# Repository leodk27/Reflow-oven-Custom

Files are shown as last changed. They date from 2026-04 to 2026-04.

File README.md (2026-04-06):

# Reflow Oven Controller  

### KES – Kwas Engineering Solutions  

---

## Overview

This is a controller for a reflow oven.  

---

## System

The system has three parts:

- Measurement (temperature)  
- Control (microcontroller)  
- Power switching (heater)  

---

## Hardware

- Microcontroller  
- Thermocouple interface  
- Triac switching stage  
- Power supply (internal and external)  

---

## Firmware

- Runs the temperature profile  
- Handles faults  
- Communicates over custom RJ45 service port  

---

## Safety

- High and low voltage are separated  
- Layout respects clearance  
- Faults lead to shutdown  

---

## Structure

- `/KICAD reflow-oven` — KiCad files  
- `/firmware` — code  
- `/docs` — notes  

---

## License

See LICENSE file.

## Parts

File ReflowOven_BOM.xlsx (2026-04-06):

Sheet: BOM_Info
KES – Bill of Materials (BOM) Template Guide
How to use this file:
- Sheet 'BOM_Template' is the clean template you copy for each new project.
- Each row is one component or module.
- Fill in at least: Quantity, Part Number, Description, Package, Supplier, Supplier Part No., Unit Price.
- You can add more columns later (e.g. Voltage Rating, Tolerance, Power).
Column | Meaning | Example Value
Item | Line number / index for reference in schematics or notes. | 1
Quantity | How many of this part are used on the PCB/assembly. | 10
Part Number | Your internal or the manufacturer’s part number. | CRCW060310K0FKEAC
Description | Short functional description. | Resistor 10 kΩ 1% 0.1 W
Package | Physical package / footprint. | 0603
Supplier | Main supplier you’ll order from. | Digi-Key
Supplier Part No. | Part number used by the supplier. | 541-10.0KHTR-ND
Unit Price | Net price per single unit (without VAT). | 0.012 €
Notes | Anything special: voltage rating, temp, critical, alt parts, etc. | Alt: Yageo RC0603FR-0710KL
Example BOM row:
Item | Quantity | Part Number | Description | Package | Supplier | Supplier Part No. | Unit Price | Notes
1 | 10 | CRCW060310K0FKEAC | Resistor 10 kΩ 1% 0.1 W | 0603 | Digi-Key | 541-10.0KHTR-ND | 0.012 | Input divider R1, keep 1%
New Columns Added:
Manufacturer | Brand or IC manufacturer | Texas Instruments
Total Cost (€) | Auto-calculated = Quantity × Unit Price | 0.12

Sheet: BOM_Template
Item | Quantity | Part Number | Manufacturer | Description | Package | Supplier | Supplier Part No. | Unit Price | Notes | Total Cost (€)
1 | 1 | MOV-14D431KTR | Bourns | MOV - series varistor | 14mm disk | digikey |  |  | https://www.bourns.com/docs/Product-Datasheets/MOV14D.pdf | 0
2 | 2 | "0031.8201" | Schurter | PCB fuse holder | 5x20mm THT | mouser | 693-0031.8201 | 0.903 | https://www.schurter.com/en/datasheet/typ_OGN.pdf | 1.806
3 | 1 | MTJ-88ARX1-FSM-LG | ADAMTECH | RJ45 PCB connector | THT | mouser | 737-MTJ88ARX1FSMLG | 1.22 | https://www.mouser.at/datasheet/3/6015/1/mtj_88arx1_fsm_lg_data_sheet.pdf | 1.22
4 |  |  |  |  |  |  |  |  |  | 0
5 |  |  |  |  |  |  |  |  |  | 0
6 | 1 | LM4030CMF-2.5/NOPB | Texas Insutrments | Shunt reference | SOT-23-5 | mouser | 926-LM4030CMF25NOPB | 1.32 | https://www.ti.com/lit/ds/symlink/lm4030.pdf?ts=1774101850147 | 1.32
7 | 1 | DMP68D1LQ-7 | Diodes Inc. | PMOS for verse polarity prot. | SOT-23-3 | mouser | 621-DMP68D1LQ-7 | 0.129 | https://www.mouser.at/datasheet/3/175/1/DMP68D1LQ.pdf | 0.129
8 | 1 | BZT52C6V8-7-F | Diodes Inc. | Zener diode 6.8V | SOD-123 | mouser | 621-BZT52C6V8-F | 0.163 | https://4donline.ihs.com/images/VipMasterIC/IC/DIOD/DIOD-S-A0003550684/DIOD-S-A0003550684-1.pdf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 | 0.163
9
10 |  |  |  |  |  |  |  |  |  | 0
11 |  |  |  |  |  |  |  |  |  | 0
12 |  |  |  |  |  |  |  |  |  | 0
13 |  |  |  |  |  |  |  |  |  | 0
14 |  |  |  |  |  |  |  |  |  | 0
15 |  |  |  |  |  |  |  |  |  | 0
16 | 1 | 890334025017CS | Würth electronics | Mains capacitor (snubber) | Radial | mouser | 710-890334025017CS | 0.378 | https://www.we-online.com/components/products/datasheet/890334025017CS.pdf | 0.378
17 |  |  |  |  |  |  |  |  |  | 0
18 |  |  |  |  |  |  |  |  |  | 0
19 |  |  |  |  |  |  |  |  |  | 0
20 |  |  |  |  |  |  |  |  |  | 0
21 |  |  |  |  |  |  |  |  |  | 0
22 | 1 | RR01J100RTB | TE connectivity | Mains resistor (snubber) | Axial-THT | mouser | 279-RR01J100RTB | 0.181 | https://www.te.com/commerce/DocumentDelivery/DDEController?Action=srchrtrv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 | 0.181
23 |  |  |  |  |  |  |  |  |  | 0
24 |  |  |  |  |  |  |  |  |  | 0
25 |  |  |  |  |  |  |  |  |  | 0
26 |  |  |  |  |  |  |  |  |  | 0
27 |  |  |  |  |  |  |  |  |  | 0
28 |  |  |  |  |  |  |  |  |  | 0
29 |  |  |  |  |  |  |  |  |  | 0
30 | 1 | NTCLE213E3103GHB0 | Vishay | NTC thermistor | long leads, bead, THT, 10k | mouser | 594-NTCLE213E3103GHB | 0.722 | https://www.vishay.com/docs/29154/ntcle213e3.pdf | 0.722
31 |  |  |  |  |  |  |  |  |  | 0
32 |  |  |  |  |  |  |  |  |  | 0
33 |  |  |  |  |  |  |  |  |  | 0
34 |  |  |  |  |  |  |  |  |  | 0
35 |  |  |  |  |  |  |  |  |  | 0
36 |  |  |  |  |  |  |  |  |  | 0
37 |  |  |  |  |  |  |  |  |  | 0
38 |  |  |  |  |  |  |  |  |  | 0
39 |  |  |  |  |  |  |  |  |  | 0
40 |  |  |  |  |  |  |  |  |  | 0
41 |  |  |  |  |  |  |  |  |  | 0
42 |  |  |  |  |  |  |  |  |  | 0
43 |  |  |  |  |  |  |  |  |  | 0
44 |  |  |  |  |  |  |  |  |  | 0
45 |  |  |  |  |  |  |  |  |  | 0
46 |  |  |  |  |  |  |  |  |  | 0
47 |  |  |  |  |  |  |  |  |  | 0
48 |  |  |  |  |  |  |  |  |  | 0
49 |  |  |  |  |  |  |  |  |  | 0
50 |  |  |  |  |  |  |  |  |  | 0

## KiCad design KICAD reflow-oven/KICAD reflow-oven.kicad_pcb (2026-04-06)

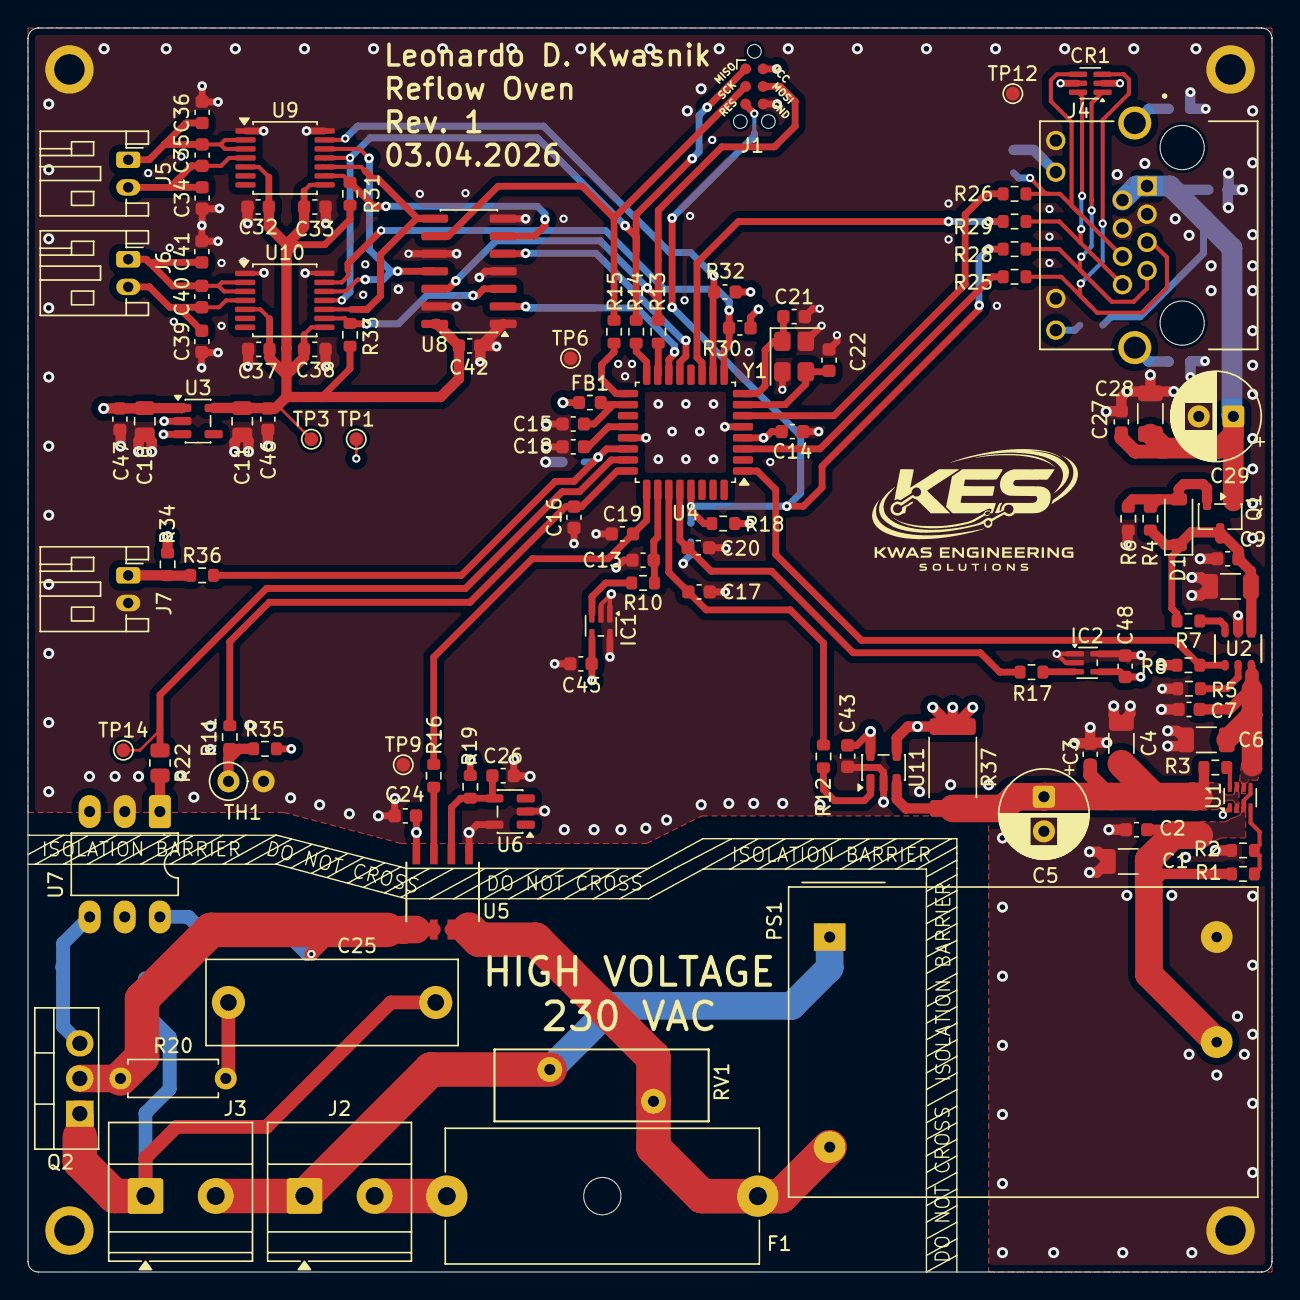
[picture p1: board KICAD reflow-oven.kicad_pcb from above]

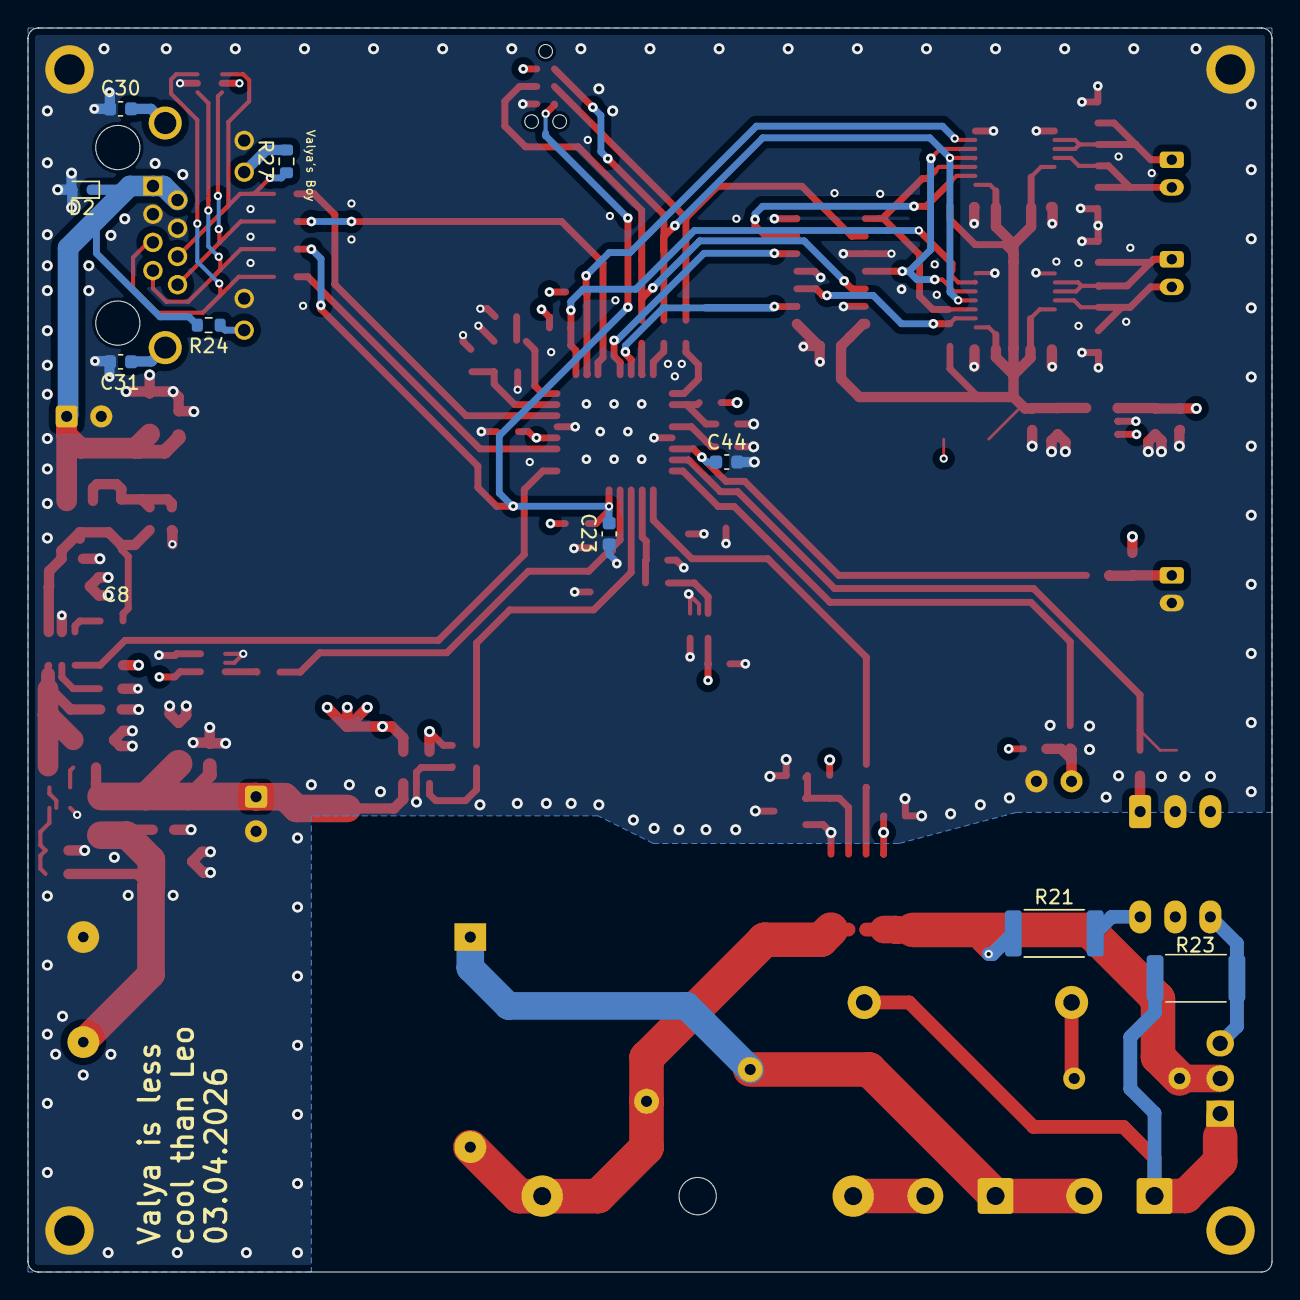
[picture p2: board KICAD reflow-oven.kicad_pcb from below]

Board: 4 copper layers, 90.0 x 90.0 mm, 124 parts (9 on the bottom side), 71 nets.

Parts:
C1, C4, C6, C8, C28: 10u; C_1206_3216Metric
C2, C3, C7, C9, C14, C15, C18, C24, C26, C27, C32, C33, C35, C37, C38, C40, C42, C43, C44, C45, C46, C47, C48: 100n; C_0603_1608Metric
C5, C29: 100u; CP_Radial_D6.3mm_P2.50mm
C10, C11: 1u; C_0805_2012Metric
C13, C16, C17, C19, C20, C34, C36, C39, C41: 10n; C_0603_1608Metric
C21, C22: 22p; C_0603_1608Metric
C23, C30, C31: 4.7n; C_0603_1608Metric
C25: 100n; C_Rect_L18.0mm_W6.0mm_P15.00mm_FKS3_FKP3
CR1: RCLAMP0504FBTCT; SOT-363_SC-70-6
D1: 6.8V; D_SOD-123
D2: ESD5Z5V; D_SOD-523
F1: Fuse; Fuseholder_Cylinder-5x20mm_Schurter_0031_8201_Horizontal_Op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
FB1: 600 @ 100M; L_0603_1608Metric
H1, H2, H3, H4: MountingHole_Pad; MountingHole_2.2mm_M2_ISO7380_Pad
IC1, IC2: TMP235AEDCKRQ1; SOT-353_SC-70-5
J1: KES-POGO_ISP_HEADER; KES_POGO_ISP_2x03_P1.27mm_Vertical
J2, J3: Screw_Terminal_01x02; TerminalBlock_Phoenix_MKDS-1,5-2-5.08_1x02_P5.08mm_Horizont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
J4: RJ45_LED_Shielded_SH1_SH2; ADAMTECH_MTJ-88ARX1-FSM-LG
J5, J6, J7: JST_PH; JST_PH_S2B-PH-K_1x02_P2.00mm_Horizontal
PS1: IRM-02-5; Converter_ACDC_MeanWell_IRM-02-xx_THT
Q1: PMOS; SOT-23-3
Q2: BTA16-600BW; TO-220-3_Vertical
R1: 360k; R_0603_1608Metric
R2, R4, R18: 100k; R_0603_1608Metric
R3, R6, R7, R8, R31, R33, R34, R35: 10k; R_0603_1608Metric
R5, R24, R27: 1k; R_0603_1608Metric
R10, R11, R12, R13, R14, R15, R16, R17, R25, R26, R28, R29: 100; R_0603_1608Metric
R19: 2.2k; R_0603_1608Metric
R20: 100; R_Axial_DIN0207_L6.3mm_D2.5mm_P7.62mm_Horizontal
R21, R23: 360; R_2512_6332Metric
R22: 220; R_0805_2012Metric
R30, R32: 10k; C_0603_1608Metric
R36: 470; R_0603_1608Metric
R37: 20m; R_2512_6332Metric
RV1: Varistor; RV_Disc_D15.5mm_W5.2mm_P7.5mm
TH1: 10k NTC; R_Axial_DIN0207_L6.3mm_D2.5mm_P2.54mm_Vertical
TP1: TP_5V; TestPoint_Pad_D1.0mm
TP3: TP_3V3; TestPoint_Pad_D1.0mm
TP6, TP9, TP12: TP_GND; TestPoint_Pad_D1.0mm
TP14: TP_HEAT_F; TestPoint_Pad_D1.0mm
U1: TPS2116DRL; SOT-583-8
U2: AP2553W6-7; SOT26_DIO
U3: TLV75533PDBV; SOT-23-5
U4: ATmega328PB-A; TQFP-32_7x7mm_P0.8mm
U5: TMCS1100A2QDR; SOIC8_D_TEX
U6: LM4030-2.5/NOPB; SOT-23-5
U7: MOC3063M; DIP-6_W7.62mm_LongPads
U8: 74LVC125; SOIC-14_3.9x8.7mm_P1.27mm
U9, U10: MAX31856; TSSOP-14_4.4x5mm_P0.65mm
U11: INA180A1; SOT-23-5
Y1: 16MHz; Crystal_SMD_3225-4Pin_3.2x2.5mm

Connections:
+3V3: C11.1, C32.1, C33.1, C37.1, C38.1, C42.2, C46.1, R31.1, R33.1, TP3.1, U3.5 (OUT), U8.14 (VCC), U9.5 (AVDD), U9.8 (DVDD), U10.5 (AVDD), U10.8 (DVDD)
+5V: C10.1, C14.2, C24.1, C43.1, C45.1, C47.1, C48.1, CR1.5, FB1.2, IC1.4 (VDD), IC2.4 (VDD), J1.2 (VCC), R8.2, R18.1, R19.1, R30.1, R32.1, R34.1, R35.1, R37.1, TP1.1, U3.1 (IN), U3.3 (EN), U4.4 (VCC), U5.8 (VS), U11.4 (-), U11.5 (V+)
/5V_CURRENT: R12.2, U11.1
/5V_TOSHUNT: C3.1, C4.1, C5.1, R3.1, R37.2, U1.2 (VOUT), U1.7 (VOUT), U11.3 (+)
/BOARD_TEMP1: IC1.3 (VOUT), R10.2
/BOARD_TEMP2: IC2.3 (VOUT), R17.2
/DOOR_STATUS: C44.1, R36.2, U4.22 (PE3)
/General_sensors/TO_REED: J7.1, R34.2, R36.1
/HEAT_control: R22.1, TP14.1, U4.23 (PC0)
/MAINS_CURRENT: R16.2, U5.7 (VOUT)
/MCU/AREF: C18.2, U4.20 (AREF)
/MCU/AVCC: C15.2, FB1.1, U4.18 (AVCC)
/MCU/MCU_MISO: R14.2, U4.16 (PB4)
/MCU/MCU_MOSI: R13.2, U4.15 (PB3)
/MCU/MCU_SCK: R15.2, U4.17 (PB5)
/MCU/PC1_A: C16.2, R11.1, U4.24 (PC1)
/MCU/PC2_A: C19.2, R16.1, U4.25 (PC2)
/MCU/PC3_A: C13.2, R10.1, U4.26 (PC3)
/MCU/PC4_A: C17.2, R12.1, U4.27 (PC4)
/MCU/PC5_A: C20.2, R17.1, U4.28 (PC5)
/MCU/XTAL1: C22.1, U4.7 (XTAL1/PB6), Y1.3
/MCU/XTAL2: C21.1, U4.8 (XTAL2/PB7), Y1.1
/MCU_MISO_R: J1.1 (MISO), R14.1, U9.11 (SDO), U10.11 (SDO)
/MCU_MOSI_R: J1.4 (MOSI), R13.1, U8.12
/MCU_SCK_R: J1.3 (SCK), R15.1, U8.9
/Mains_switching/AC_L_FUSED: F1.1, PS1.2 (AC/L), RV1.1, U5.3 (IN-), U5.4 (IN-)
/Mains_switching/AC_L_IN: F1.2, J2.2
/Mains_switching/AC_L_TO_HEATER: C25.2, J3.1, Q2.1 (A1), R23.1
/Mains_switching/AC_L_TO_TRIAC: Q2.2 (A2), R20.1, R21.1, U5.1 (IN+), U5.2 (IN+)
/Mains_switching/AC_N: J2.1, J3.2, PS1.1 (AC/N), RV1.2
/Mains_switching/AC_T_GATE: Q2.3 (G), R23.2, U7.4
/Mains_switching/OPTOT_LED: R22.2, U7.1
/Mains_switching/OPTOT_OUT: R21.2, U7.6
/Mains_switching/SNUBBER: C25.1, R20.2
/Mains_switching/TMCS_VREF: C26.1, R19.2, U5.6 (VREF), U6.4 (VREF)
/Power_management/AP2553_EN: R7.1, U2.3 (EN)
/Power_management/AP2553_ILIM: R5.1, U2.5 (ILIM)
/Power_management/TPS_PR1: R1.2, R2.1, U1.4 (PR1)
/Power_management/TPS_ST: R3.2, U1.8 (ST)
/Power_management/VBUS_F1: C8.1, C9.1, D1.1 (K), Q1.3 (S), R4.1, R7.2, U2.1 (IN)
/Power_management/VBUS_F2: C6.1, C7.1, U1.6 (VIN2), U2.6 (OUT)
/Power_management/VBUS_PROT_G: D1.2 (A), Q1.2 (G), R4.2, R6.1
/RESET: C23.1, J1.5 (RESET), R18.2, R28.1, U4.29 (~RESET/PC6)
/RJ45_input/RJ45_LED_1: J4.12, R24.1
/RJ45_input/RJ45_LED_2: J4.10, R27.1
/RJ45_input/RJ45_RESET: CR1.1, J4.7, R28.2
/RJ45_input/RJ45_RX: CR1.3, J4.5, R25.2
/RJ45_input/RJ45_SERVICE: CR1.6, J4.8, R29.2
/RJ45_input/RJ45_TX: CR1.4, J4.6, R26.2, R27.2
/RJ45_input/SH1: C31.2, J4.SH1
/RJ45_input/SH2: C30.2, J4.SH2
/SERVICE_IO: R29.1, U4.11 (PD7)
/TC1_CS: U4.14 (PB2), U8.2
/TC1_FAULT: R30.2, U4.10 (PD6), U9.13 (~FAULT)
/TC2_CS: U4.13 (PB1), U8.5
/TC2_FAULT: R32.2, U4.9 (PD5), U10.13 (~FAULT)
/TRIAC_TEMP: R11.2, R35.2, TH1.1
/Thermocouple_inputs/MAX_MOSI: U8.11, U9.12 (SDI), U10.12 (SDI)
/Thermocouple_inputs/MAX_SCK: U8.8, U9.10 (SCK), U10.10 (SCK)
/Thermocouple_inputs/TC1_CS_MAX: R33.2, U8.3, U10.9 (~CS)
/Thermocouple_inputs/TC2_CS_MAX: R31.2, U8.6, U9.9 (~CS)
/Thermocouple_inputs/TC_1_T+: C34.2, C35.1, J5.2, U9.4 (T+)
/Thermocouple_inputs/TC_1_T-: C35.2, C36.1, J5.1, U9.2 (BIAS), U9.3 (T-)
/Thermocouple_inputs/TC_2_T+: C39.2, C40.1, J6.2, U10.4 (T+)
/Thermocouple_inputs/TC_2_T-: C40.2, C41.1, J6.1, U10.2 (BIAS), U10.3 (T-)
/UART1_RX: R25.1, U4.3 (PE0)
/UART1_TX: R26.1, U4.6 (PE1)
/VBUS: C27.2, C28.1, C29.1, D2.1 (K), J4.1, J4.2, Q1.1 (D), R24.2
/VBUS_FAULT: R8.1, U2.4 (FAULT), U4.1 (PD3)
/VPSU: C1.1, C2.1, PS1.4 (+Vo), R1.1, U1.3 (VIN1), U1.5 (MODE)
GND: C1.2, C2.2, C3.2, C4.2, C5.2, C6.2, C7.2, C8.2, C9.2, C10.2, C11.2, C13.1, C14.1, C15.1, C16.1, C17.1, C18.1, C19.1, C20.1, C21.2, C22.2, C23.2, C24.2, C26.2, C27.1, C28.2, C29.2, C30.1, C31.1, C32.2, C33.2, C34.1, C36.2, C37.2, C38.2, C39.1, C41.2, C42.1, C43.2, C44.2, C45.2, C46.2, C47.2, C48.2, CR1.2, D2.2 (A), H1.1, H2.1, H4.1, IC1.1 (NC), IC1.2 (GND), IC1.5 (NC), IC2.1 (NC), IC2.2 (GND), IC2.5 (NC), J1.6 (GND), J4.3, J4.4, J4.9, J4.11, J7.2, PS1.3 (-Vo), R2.2, R5.2, R6.2, TH1.2, TP6.1, TP9.1, TP12.1, U1.1 (GND), U2.2 (GND), U3.2 (GND), U4.5 (GND), U4.21 (GND), U5.5 (GND), U6.2 (NC), U6.5 (GND), U7.2, U8.1, U8.4, U8.7 (GND), U8.10, U8.13, U9.1 (AGND), U9.14 (DGND), U10.1 (AGND), U10.14 (DGND), U11.2 (GND), Y1.2 (G), Y1.4 (G)

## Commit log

2026-04-06 Update .gitignore for KiCad and OS junk files
2026-04-06 Extra file cleanup
    [freerouting.dsn]
